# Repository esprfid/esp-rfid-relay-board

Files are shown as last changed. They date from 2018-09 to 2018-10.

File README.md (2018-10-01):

# ESP-RFID Relay Board

This project is follow up for "ESP-RFID Board" but with few more options.

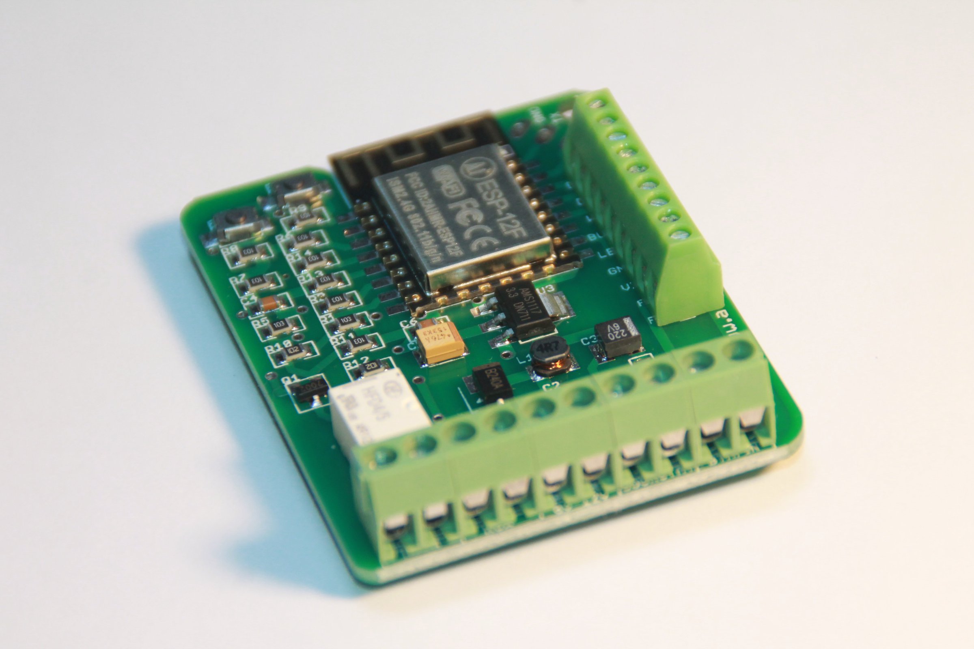
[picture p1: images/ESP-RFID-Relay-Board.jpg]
&nbsp;&nbsp;

## What is ESP-RFID Relay Board?
ESP-RFID Relay Board is tiny ESP12 module (ESP8266) board, designed with wiegand RFID readers in mind and [ESP-RFID Firmware](https://github.com/esprfid/esp-rfid)

* Small size factor, sometimes possible to glue it into existing readers.
* Single power source to power 12V/2A powers ESP12 module, RFID Wiegand Reader and magnetic lock for opening doors.
* Exposed programming pins for ESP8266
* Due to interesting hardware design, you get multiple possible setup options:
  * Forward Bell ringing on reader to MCU or pass it out of board
  * Track Door Status
  * Control reader’s status LED
  * Control reader’s status BUZZER sound
  * Power reader, lock and the board through single 12V, 2A PSU
  * Optionally power magnetic lock through external AC/DC PSU
  * Possible to use any kind and any type of wiegand readers
  * Enables you to make IOT Access System with very litle wiring
  * Fit in universal enclosures with DIN mount
* Opensource Hardware/Cloud RFID reader/Wifi RFID reader

## Wiring example:

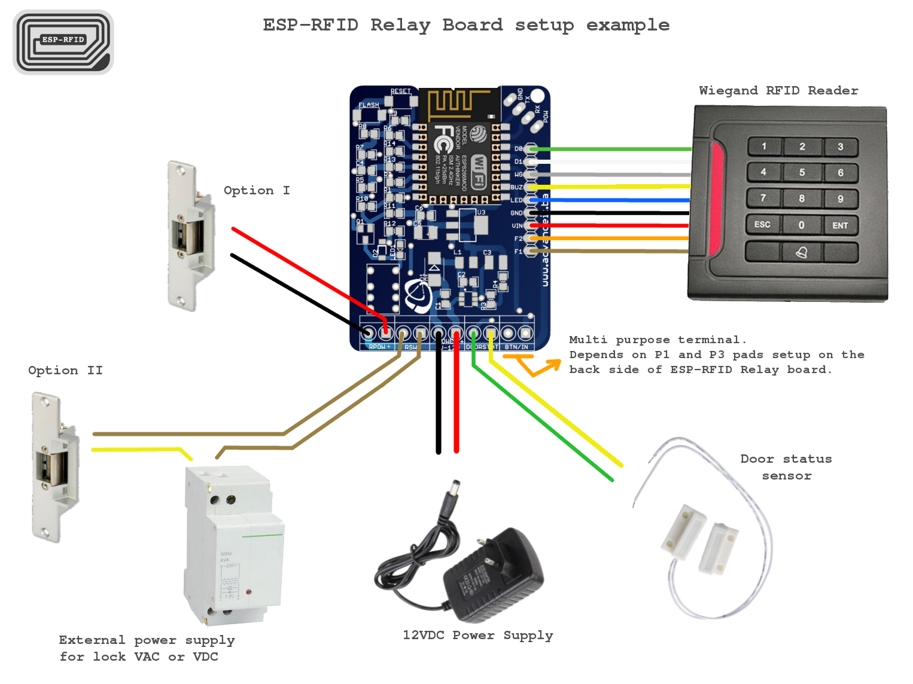
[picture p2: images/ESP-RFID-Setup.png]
&nbsp;&nbsp;

## RESET and FLASH Buttons
Same as for any other ESP8266 programmer where you need to put EPS8266 into a specific mode. If you want to upload your program, you would use this buttons to put ESP8266 into FLASH mode. Check programming procedure down.

## Reader 9 pin terminal
The reason for 9 pins is to cover the most complex wiegand reader i could fins on the market. Mostly they only have 5 or 6 wires but sometimes, they also have 9 wire versions.

**PINNAME**|**CONNECTION**|**DESCRIPTION**
:-----|:-----|:-----
**DO**|GPIO4|Wiegand data line **D0** (*)
**D1**|GPIO5|Wiegand data line **D1**. (*)
**WG**|GPIO0|Some readers have WG line which if HIGH/LOW can change Wiegand stream bits. Usually not very important!
**BUZ**|GPIO12|Almost always Wiegand RFID Readers have Buzzer line which can control piezo buzzer. Due to some inconsistency among readers, i was able to make it work only when i connect this line through 10K resistor and than control it with changing HIGH/LOW on that particular pin, depending what i want. IMPORTANT: **P3** Pad on the back of board, can make that line to be connected directly to GPIO or through 10k resistor. Check **P3** Pad explanation.
**LED**|GPIO15|Most Wiegand readers have RED/GREEN status LEDs. Some color is default and if the line is changed HIGH/LOW than the other color appears.
**GND**|GND|Planned for Wiegand RFID Reader GND.
**VIN**|VIN|Connected directly to board’s POWER terminal’s positive pole. (*)
**F2**|To BTN/IN terminal left pole or to  GPIO14 (**)|Rarely Wiegand RFID Readers incorporate one button which is often doorbell switch, but the version that i took as an example for this board has those wires. It’s simply the switch between F1/F2.
**F1**|To BTN/IN terminal right pole or to GPIO14 (**)|

## Screw Terminals On the bottom of ESP-RFID Relay Board

**TERMINAL NAME**|**DESCRIPTION**
:-----|:-----
**RPOW**|In case **RELAY-POWER** pad is connected, when relay connects the circuit, this terminal provides input voltage directly on it’s poles. So the door magnet lock can be powered directly through this terminal.
**RSW**|Since i used small signal relay, it had two sides so another side is also connecting at the same time when relay makes connection but it only cut circuit. So practical use for this terminal can be to power magnetic lock with external source and even AC so that you get buzzing sound when the lock opens and avoid jamming of the lock. (*)
**POWER 8V-12V**|This is the main power source and in some settings only power source that you need. Please provide minimum 2A if you also power magnetic lock and Wiegand RFID Reader from same source, through ESP-RFID Relay Board
**DOORSTAT**|This terminal was planned to accept door status magnet switch. It can be also repurposed since it’s just a "button" connected to **GPIO16**.
**BTN/IN**|Depending on **P1** and **P2** Pads connection, it can have different purposes.Check **P2/P3** pads description below.

## Configuration pads P1, P2, P3, RELAY-POWER, 5V/3V3

**PAD NAME**|**DESCRIPTION**
:-----|:-----
**P1**|**Options:** Connected poles **3** and **2** redirects **F1** on **RFID Reader Terminal** to **BTN/IN** right pole. Connected poles 3 and 1 and you will get **GPIO14** to be connected on left **BTN/IN** terminal, grounded with 10k resistor. Connected poles **2** and **1** and you will power pin **F1** on **RFID Reader Terminal** with **GPIO14** (*)
**P2**|**Options:** Connected poles **3** and **2** redirects **F2** on  RFID Reader Terminal to BTN/IN left pole. Connected poles 3 and 1 and you will get 3V3 on left pin of BTN/IN terminal. Connected poles **2** and **1** and you will power pin **F2** on **RFID Reader Terminal** with 3V3 (*)
**P3**|**Options:** Connected poles **1** and **2** redirects **BUZ** pin on **RFID Reader Terminal** and **GPIO12**. Connected poles **2** and **3** redirects **BUZ** pin on **RFID Reader Terminal** and **GPIO12** through 10K resistor.
**RELAY-POWER**| This pad is usually connected if you want to power **RPOW** Terminal from main power source as **ESP-RFID Relay Board**
**5V/3V3**|Only purpose of this pad is to connect 5V or 3V3 line to **PROG’s** **POW** pin.

## Pads and what was the idea.
The main idea was to be able to adjust this little board to your scenario and also not  to occupy few GPIO where there is possibility to use those in some other way.

For example, i thought that somebody would like to have remote doorbell but somebody would simple hook it directly. Yet, it might happen that you don’t need doorbell at all but you might find use for GPIO14. So, i made custom PCB Three Way Pad.

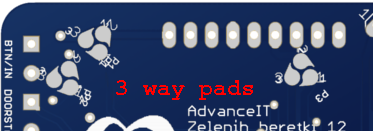
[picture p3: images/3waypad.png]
&nbsp;&nbsp;

Find out about it here:  
https://hackaday.io/project/54277-3-way-pcb-pad  
https://github.com/nardev/eagle3wayPCBpads  
So, it’s similar to other pads which you just solder but this pad has unique shape so it can be soldered not in 2 but in 3 different ways. Just solder it in a way you want. (*) Check the table with description above.

**P1 and P2** pads must be set in pair. Essentially you can get one of three different options.  
**I** : You can redirect F1 and F2 on RFID Reader Terminal to BTN/IN terminal.  
**II**: You can redirect input on F1 and F2 on RFID Reader Terminal to ESP8266’s GPIO14.  
**III**: You can redirect BTN/IN terminal to ESP8266’s GPIO14 as button input.  

**P3** has bit strange purpose. I noticed that most popular wiegand readers have BUZZER line which i couldn’t control directly by simply HIGH/LOW on digital pins of ESP8266 and i also couldn’t  find any docs what signal is required, but i found a way for most of readers, it’s simply to put 10K resistor on the line. But, since it varies i also left an option to hook it directly to GPIO12  

**RELAY-POWER** is just connecting positive line to RPOW terminal. Usually, if you power the lock from the ESP-RFID Relay Board, that pad will be connected and you will use RPOW terminal to hook the lock.  

**5V/3V3** pad can be handy if you are powering ESP12F module through programmer itself while programming.  

## Relay
The relay used on this board is HFD4/5, DPST signal relay and it’s controlled through **GPIO13** on ESP8266.

## PROGRAMMING
#### Programming procedures and options.

**ESP-RFID relay Board** is essentially dev board extension for **ESP12** modules. As that, it has **RESET** and **FLASH** buttons and the rest of circuit required to put ESP8266 in programming mode.
In order to program the board, you would need **"USB-TTL"** or similar compatible programmer. (I personally like this 1$ one [here](https://www.electrodragon.com/product/usb-ttl-serial-ch340-board/))

**Programming Procedure**

Considering that you already installed required drivers for your OS and that you have programming software already set, follow procedure:
1. Connect your **USB-TTL** programmer to P ROG terminal. (Don’t forget to cross lines, RX to TX and vice versa)
2. Press **FLASH** and **RESET** buttons together.
3. Release **RESET** Button and keep **FLASH** Button pressed for 1-2 sec and than release it too.
4. Now, your ESP8266 should be in **FLASH** mode and you can upload you program.
(*) I noticed that it it doesn’t make any problems if you keep **FLASH** Button pressed and sometimes **ESP8266** won’t start with **FLASH** mode in any other way.

## KNOWN ISSUES
* Silkscreen mistake WG/LED pins should be switched. (To test with base
firmware and setting pins to down/up and to check if that is the case only with
ESP-RFID firmware)

* Sometimes, connected ringing button through board, VAC source and to bell,
causes buck converter to jamm. It could be due to poor wire quality or something
else. But usually if it doesn’t occur immediately on first try, it never appears later.

## Short video walk-through

ESP8266 RFID Wiegand ESP12 Nodemcu (https://youtu.be/rXRt-YkzXZU)

### You can get this board from my Tindie shop:
<a href="https://www.tindie.com/products/nardev/esp-rfid-relay-board-12v-for-esp8266-board/">

</a>

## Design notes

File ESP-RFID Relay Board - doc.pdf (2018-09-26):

## ESP-RFID Relay Board v2.0

ESP-RFID Relay Board is tiny ESP12 module (ESP8266) board, designed with wiegand RFID readers in mind.

■ Small size factor, sometimes possible to glue it into existing readers.
■ Single power source to power 12V/2A powers ESP12 module, RFID Wiegand Reader and magnetic lock for opening doors.
■ Exposed programming pins for ESP8266
■ Regarding hardware design, you get multiple possible setup options:
- Forward Bell ringing on reader to MCU or pass it out of board
- Track Door Status
- Control reader’s status LED
- Control reader’s status BUZZER sound *
- Power reader, lock and the board through single 12V, 2A PSU
- Optionally power magnetic lock through external AC/DC PSU
- Possible to use any kind and any type of wiegand readers
- Enables you to make IOT Access System with very litle wiring ■ Fit in universal enclosures with DIN mount
■ Opensource Hardware
■ Optionally comes with Opensource “esp-rfid” firmware which makes it “single door control” ready device with possibility to add rfid access cards or tokens and handle access systems.

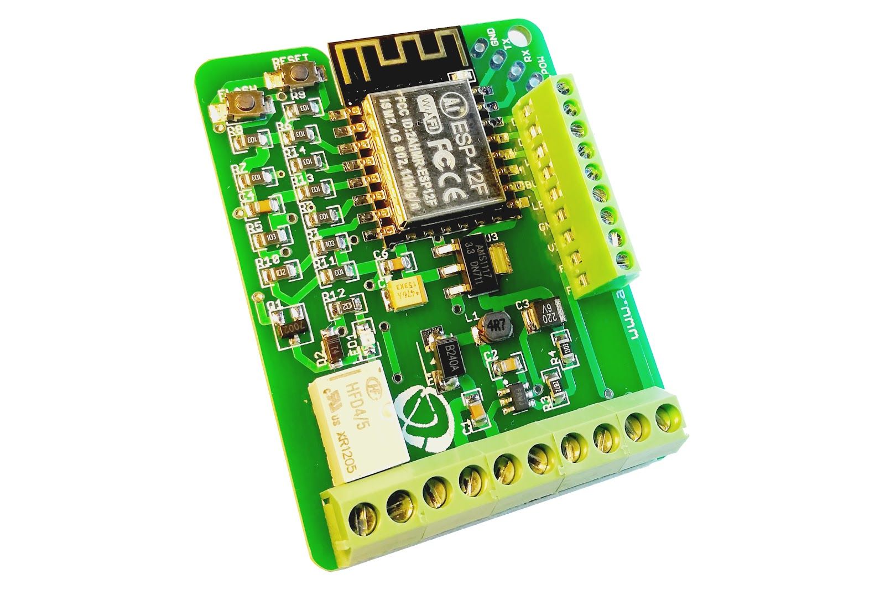
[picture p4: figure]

* This is atypical technical documentation, with a purpose to explain every single part on the board and it’s properties. It’s based mostly on tests and other technical docs for parts that had been used on the board.

AdvanceIT | - ADDRESS: | Džemala Bijedića 129 B/C, Sarajevo, Bosnia & Herzegovina
EMAIL: support@advanceit.ba | TEL: +387 61 107 423 FAX: +387 33 215 206

## HARDWARE EXPLAINED

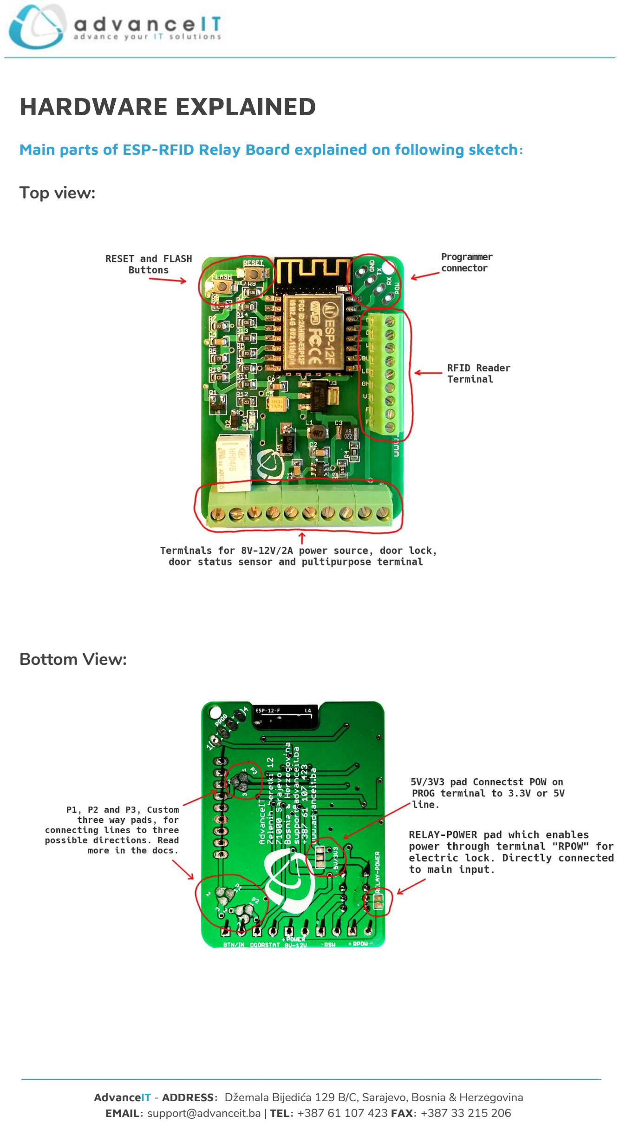
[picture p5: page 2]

Main parts of ESP-RFID Relay Board explained on following sketch:

Top view:

Bottom View:

RESET and FLASH Buttons

Same as for any other ESP8266 programmer where you need to put EPS8266 into a specific mode. If you want to upload your program, you would use this buttons to put ESP8266 into FLASH mode. Check programming procedure down.

RFID Reader Terminal

The reason for 9 pins is to cover the most complex wiegand reader i could fins on the market. Mostly they only have 5 or 6 wires but sometimes, they also have 9 wire versions.

This particular model of Wiegand RFID Reader has 9 wires and 9 pin connector on ESP-RFID Relay Board can handle all those lines.

PIN NAME | CONNECTION | DESCRIPTION
DO | GPIO4 | Wiegand data line D0 (*)
D1 | GPIO5 | Wiegand data line D1. (*)
WG | GPIO0 | Some readers have WG line which if HIGH/LOW can change Wiegand stream bits. Usually not very important!
BUZ | GPIO12 | Almost always Wiegand RFID Readers have Buzzer line which can control piezo buzzer. Due to some inconsistency among readers, i was able to make it work only when i connect this line through 10K resistor and than control it with changing HIGH/LOW on that particular pin, depending what i want. IMPORTANT: P3 Pad on the back of board, can make that line to be connected directly to GPIO or through 10k resistor. Check P3 Pad explanation.
LED | GPIO15 | Most Wiegand readers have RED/GREEN status LEDs. Some color is default and if the line is changed HIGH/LOW than the other color appears.
GND | GND | Planned for Wiegand RFID Reader GND.
VIN | VIN | Connected directly to board’s POWER terminal’s positive pole. (*)
F2 | To BTN/IN terminal left pole or to GPIO14 (**) | Rarely Wiegand RFID Readers incorporate one button which is often doorbell switch, but the version that i took as an example for this board has those wires. It’s simply the switch between F1/F2.
F1 | To BTN/IN terminal right pole or to GPIO14 (**)

(*) Usually Wiegand RFID Readers can work with 8V to 12V as the ESP-RFID relay Board. So, single power supply directly powers both devices.

(**) F1/F2 can be transferred to BTN/IN terminal or to GPIO14, depending on P1/P2 configuration. Check P1/P2 Pads configuration properties below.

Screw Terminals On the bottom of ESP-RFID Relay Board

TERMINAL NAME | DESCRIPTION
RPOW | In case RELAY-POWER pad is connected, when relay connects the circuit, this terminal provides input voltage directly on it’s poles. So the door magnet lock can be powered directly through this terminal.
RSW | Since i used small signal relay, it had two sides so another side is also connecting at the same time when relay makes connection but it only cus circuit. So practical use for this terminal can be to power magnetic lock with external source and even AC so that you get buzzing sound when the lock opens and avoid jamming of the lock. (*)
POWER 8V-12V | This is the main power source and in some settings only power source that you need. Please provide minimum 2A if you also power magnetic lock and Wiegand RFID Reader from same source, through ESP-RFID Relay Board
DOORSTAT | This terminal was planned to accept door status magnet switch. It can be also repurposed since it’s just a “button” connected to GPIO16.
BTN/IN | Depending on P1 and P2 Pads connection, it can have different purposes.Check P2/P3 pads description below.

Configuration pads P1, P2, P3, RELAY-POWER, 5V/3V3

PAD NAME | DESCRIPTION
P1 | Options: ■ Connected poles 3 and 2 redirects F1 on RFID Reader Terminal to BTN/IN right pole. ■ Connected poles 3 and 1 and you will get GPIO14 to be connected on left BTN/IN terminal, grounded with 10k resistor. ■ Connected poles 2 and 1 and you will power pin F1 on RFID Reader terminal with GPIO14 (*)
P2 | Options: ■ Connected poles 3 and 2 redirects F2 on RFID Reader Terminal to BTN/IN left pole. ■ Connected poles 3 and 1 and you will get 3V3 on left pin of BTN/IN terminal. ■ Connected poles 2 and 1 and you will power pin F2 on RFID Reader terminal with 3V3 (*)
P3 | Options: ■ Connected poles 1 and 2 redirects BUZ pin on RFID Reader Terminal and GPIO12. ■ Connected poles 2 and 3 redirects BUZ pin on RFID Reader terminal and GPIO12 through 10K resistor.
RELAY-POWER | This pad is usually connected if you want to power RPOW Terminal from main power source as ESP-RFID Relay Board
5V/3V3 | Only purpose of this pad is to connect 5V or 3V3 line to PROG’s POW pin.

Pads and what was the idea.
The main idea was to be able to adjust this little board to your scenario and also not to occupy few GPIO where there is possibility to use those in some other way.

For example, i thought that somebody would like to have remote doorbell but somebody would simple hook it directly. Yet, it might happen that you don’t need doorbell at all but you might find use for GPIO14. So, i made custom PCB Three Way Pad.

Find out about it here:
https://hackaday.io/project/54277-3-way-pcb-padhttps://github.com/nardev/eagle3wayPCBpads

So, it’s similar to other pads which you just solder but this pad has unique shape so it can be soldered not in 2 but in 3 different
ways. Just solder it in a way you want. (*) Check the table with
description above.

P1 and P2 pads must be set in pair. Essentially you can get one of three different options.
I : You can redirect F1 and F2 on RFID Reader Terminal to BTN/IN terminal.
II: You can redirect input on F1 and F2 on RFID Reader Terminal to ESP8266’s GPIO14.
III: You can redirect BTN/IN terminal to ESP8266’s GPIO14 as button input.

P3 has bit strange purpose. I noticed that most popular wiegand readers have BUZZER line which i couldn’t control directly by simply HIGH/LOW on digital pins of ESP8266 and i also couldn’t find any docs what signal is required, but i found a way for most of readers, it’s simply to put 10K resistor on the line. But, since it varies i also left an option to hook it directly to GPIO12

RELAY-POWER is just connecting positive line to RPOW terminal. Usually, if you power the lock from the ESP-RFID Relay Board, that pad will be connected and you will use RPOW terminal to hook the lock.

5V/3V3 pad can be handy if you are powering ESP12F module through programmer itself while programming.

Relay

The relay used on this board is HFD4/5, DPST signal relay and it’s controlled through GPIO13 on ESP8266.

## BOARD USAGE OPTIONS

“While designing, the idea was to minimize wiring but to provide few more options which could be useful for some installations.”

What is where on the board:

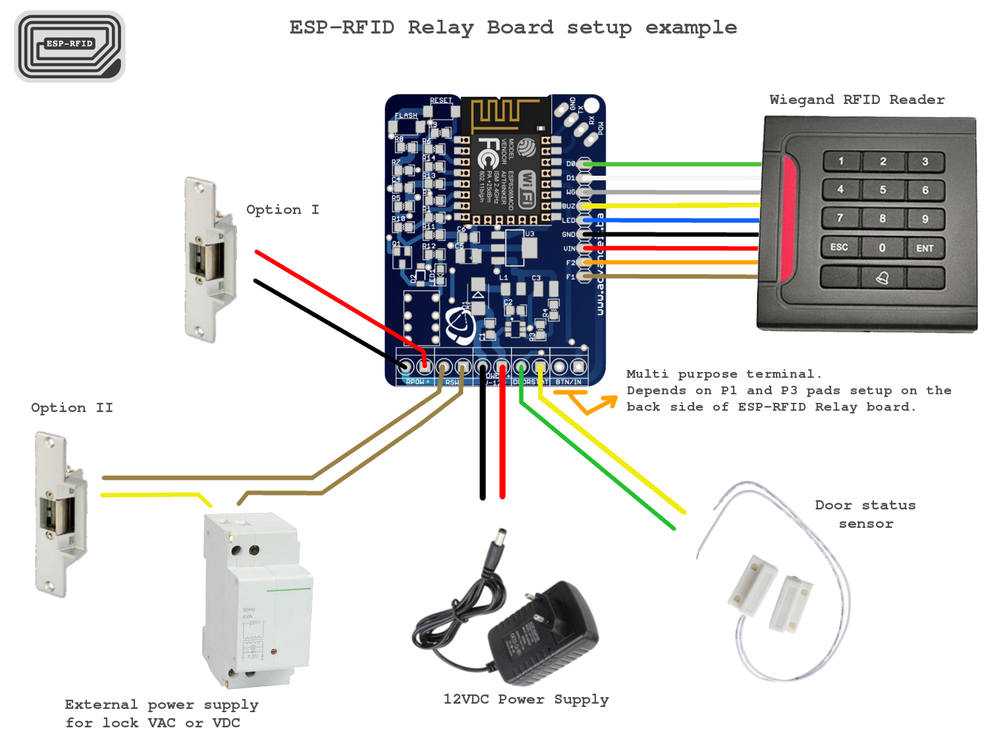
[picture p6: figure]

## I. Most Common Case

■ Single power source 12VDC/2A
■ RFID reader powered directly from the ESP-RFID Board v2.0 ■ Door lock powered directly from the ESP-RFID Board v2.0

[IMAGE/DESCRIPTION COMING SOON]

II. With additional AC Power for Door Lock

■ Main power source 12VDC/2A
■ RFID reader powered directly from the ESP-RFID Board v2.0 ■ Door lock powered directly from the ESP-RFID Board v2.0

[IMAGE/DESCRIPTION COMING SOON]

III. Optional Features

Door status sensor
[IMAGE/DESCRIPTION COMING SOON]

Ring button forward to ESP
Ring button forward to ESP8266

Ring screw terminal as input for sensor or a button
In case it’s not used to forward RING button or Ring is not forwarded to ESP8266, by soldering P1 and P2 …… You can use “BTN/IN” terminal as input to ESP8266.

BUZZER Control
Due to strange behaviour of buzzer, there is there is PAD which can connect the BUZ pin directly to GPIO or through 10K resistor.
[IMAGE/DESCRIPTION COMING SOON]

## POWER SPECIFICATIONS

Power Specifications
There is three levels of voltage on the board. Main input, 5V and 3.3V. Check the description:
Segment | Type of Device | Current/Voltage | Purpose on the board
Required general Input | General purpose 12VDC source | 2A/12V | Main input. Powers everything hooked to a board: - Wiegand RFID reader (~0.5A peak) - ESP-RFID Board (up to 1A max) - Buck Converter - Linear 3V3 Voltage Regulator - Door magnet lock (usually up to 0.5A)
Buck converter | ACT4088 | Lower 12V to 5V / up to ~1A | Power up: - Linear 3V3 Voltage Regulator - Provide 5v for Relay * Possible to pass it to programmer terminal
Linear voltage regulator | LM1117 | Lower 5V to 3.3V / up to ~0.5A | Powering ESP12 module and it’s IO’s. (*) Possible to pass it to programmer terminal
External Power for Relay | AC/DC | 18V/2A | Optional, only if powering door lock or ring.

(*) Please check “5V/3V3” pad purpose.

## PROGRAMMING

Programming procedures and options.
ESP-RFID v2 is essentially dev board extension for ESP12 modules. As that, it has RESET and FLASH buttons and the rest of circuit required to put ESP8266 in programming mode.

In order to program the board, you would need “USB-TTL” or similar compatible programmer. (I personally like this 1$ one here) (http://www.electrodragon.com/product/usb-ttl-serial-ch340-board/)

Programming Procedure

Considering that you already installed required drivers for your OS and that you have programming software already set, follow procedure:

1. Connect your USB-TTL programmer to PROG terminal.
(Don’t forget to cross lines, RX to TX and vice versa)
2. Press FLASH and RESET buttons together.
3. Release RESET Button and keep FLASH Button pressed for 1-2 sec and than release it too.
4. Now, your ESP8266 should be in FLASH mode and you can upload you program.

(*) I noticed that it it doesn’t make any problems if you keep FLASH Button pressed and sometimes ESP8266 won’t start with FLASH mode in any other way.

## KNOWN ISSUES

■ Silkscreen mistake WG/LED pins should be switched. (To test with base firmware and setting pins to down/up and to check if that is the case only with ESP-RFID firmware)
■ Sometimes, connected ringing button through board, VAC source and to bell, causes buck converter to jamm. It could be due to poor wire quality or something else. But usually if it doesn’t occur immediately on first try, it never appears later.

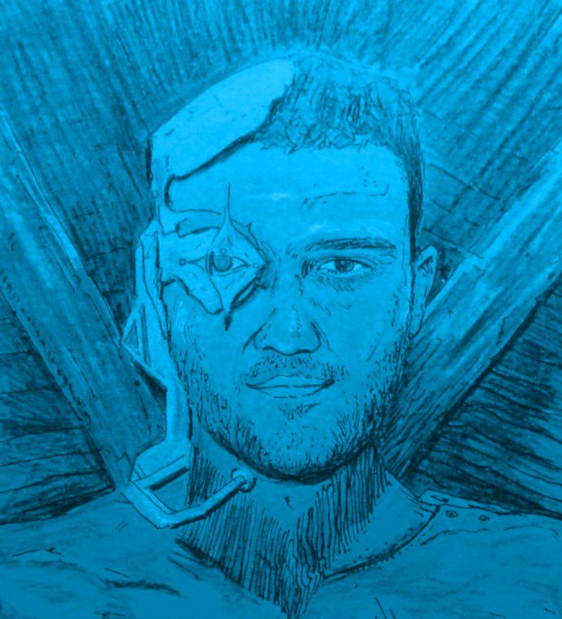
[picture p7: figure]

CONTACT
+387 61 107 423

vedran@advanceit.ba

Džemala Bijedića 129 B/C , Bosnia & Herzegovina

www.advanceit.ba

SOCIAL MEDIA
@e74av (https://www.instagram.com/sfera_antenna/)

@_E74AV_

Vedran Alajbegovic

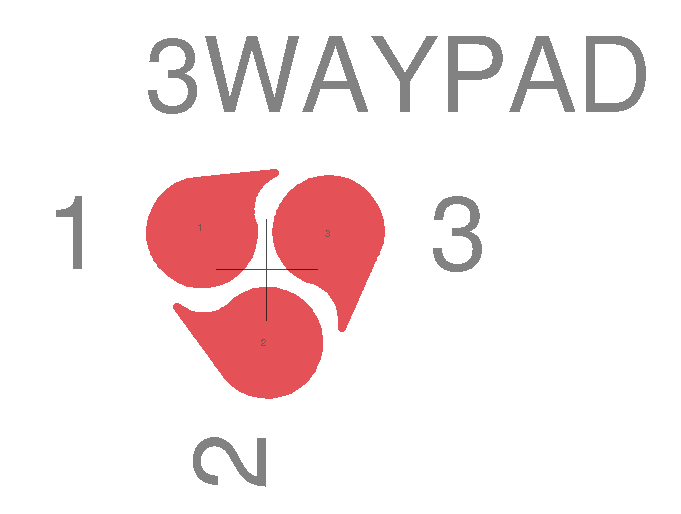
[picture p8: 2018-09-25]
images/3waypadshape.png

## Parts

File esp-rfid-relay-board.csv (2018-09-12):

Part | Value | Device | Package | Description
C1 | 100n | C-EUC0805 | C0805K | CAPACITOR, European symbol
C3 | 22nF | C-EUC0805 | C0805K | CAPACITOR, European symbol
C4 | 10uF | C-EUC0805 | C0805K | CAPACITOR, European symbol
C5 | 220uF | C-EUC1210 | C1210 | CAPACITOR, European symbol
C6 | 0.1uF | C-EUC0805 | C0805K | CAPACITOR, European symbol
D1 |  | SCHOTTKY-DIODESMD | SMB | B240A
D3 | 4007-4148 | DIODESOD123FL | DIO_SOD123FL | 1N4148
L1 | 4.7uH | L-EUL3225M | L3225M | Inductor, can be shielded one if you have.
OP1 |  | LED0805LED | 0805LED | A Led for relay, any color
Q1 |  | MOSFET_NSOT23 | SOT23 | Power MOSFET N-Channel for relay
R7 | 150K | RESISTORR0805 | R0805
R8 | 28.7K | RESISTORR0805 | R0805
R9 | 102R | RESISTORR0805 | R0805
R10 | 15K | RESISTORR0805 | R0805
R12 | 1K / 102R | RESISTORR0805 | R0805
R11 | 10K / 103R | RESISTORR0805 | R0805 | SAME 10K resistors 9
R13 | 10K | RESISTORR0805 | R0805
R14 | 10K | RESISTORR0805 | R0805
R1 | 10K | RESISTORR0805 | R0805
R2 | 10K | RESISTORR0805 | R0805
R3 | 10K | RESISTORR0805 | R0805
R4 | 10K | RESISTORR0805 | v
R5 | 10K | RESISTORR0805 | R0805
R6 | 10K | RESISTORR0805 | R0805
RESET | RESET | BUTTON-2PSWITCH-TURTLE-2P | 2P-SWITCH-TURTLE | Small turtle buttons
FLASH | FLASH | BUTTON-2PSWITCH-TURTLE-2P | 2P-SWITCH-TURTLE
RELAY | 2XSWITCH | 2XSWITCH | HFD3-SIGNAL | Relay HFD3/5V MUST BE 5V version!!!
U2 |  | POWERSOT223 | SOT223 | Voltage Regulator LM1117
BUCKCONV | AIC1896CG-SOT23-6 | ACT4088-(SOT23-6) | SOT-23-6 | ACT4088

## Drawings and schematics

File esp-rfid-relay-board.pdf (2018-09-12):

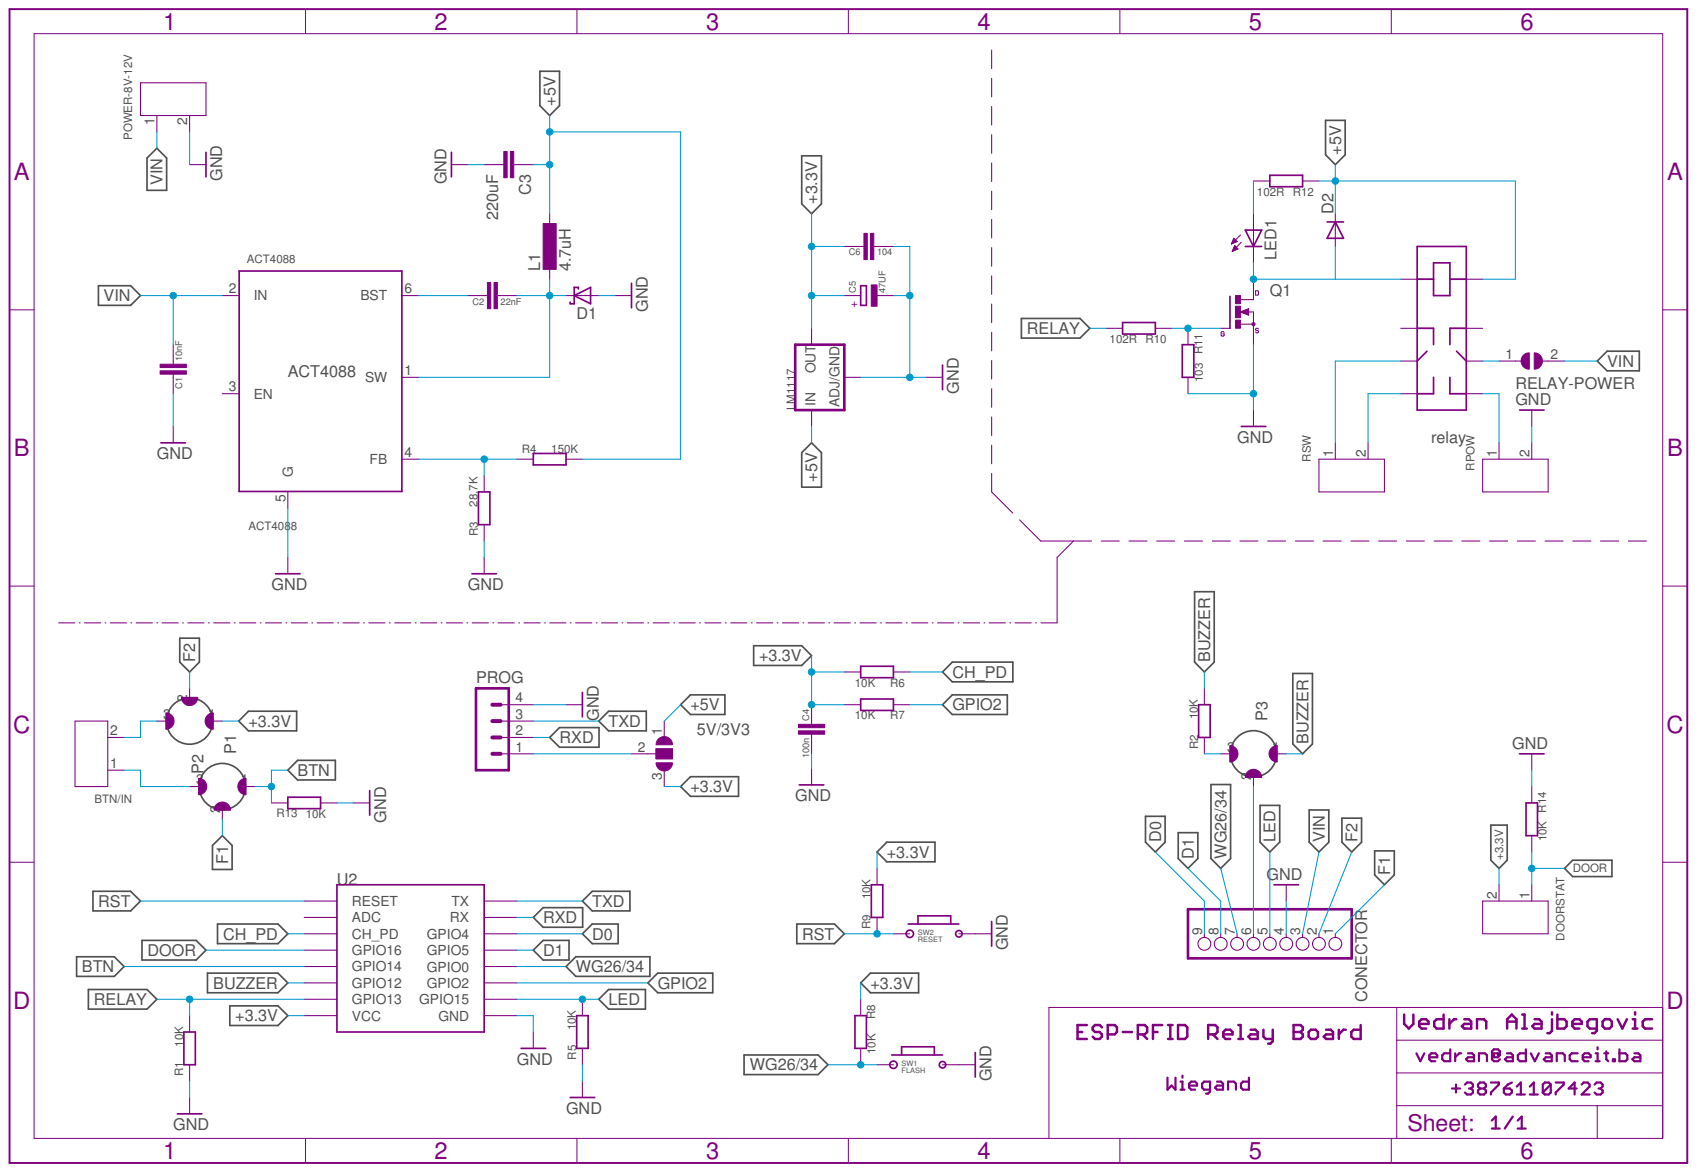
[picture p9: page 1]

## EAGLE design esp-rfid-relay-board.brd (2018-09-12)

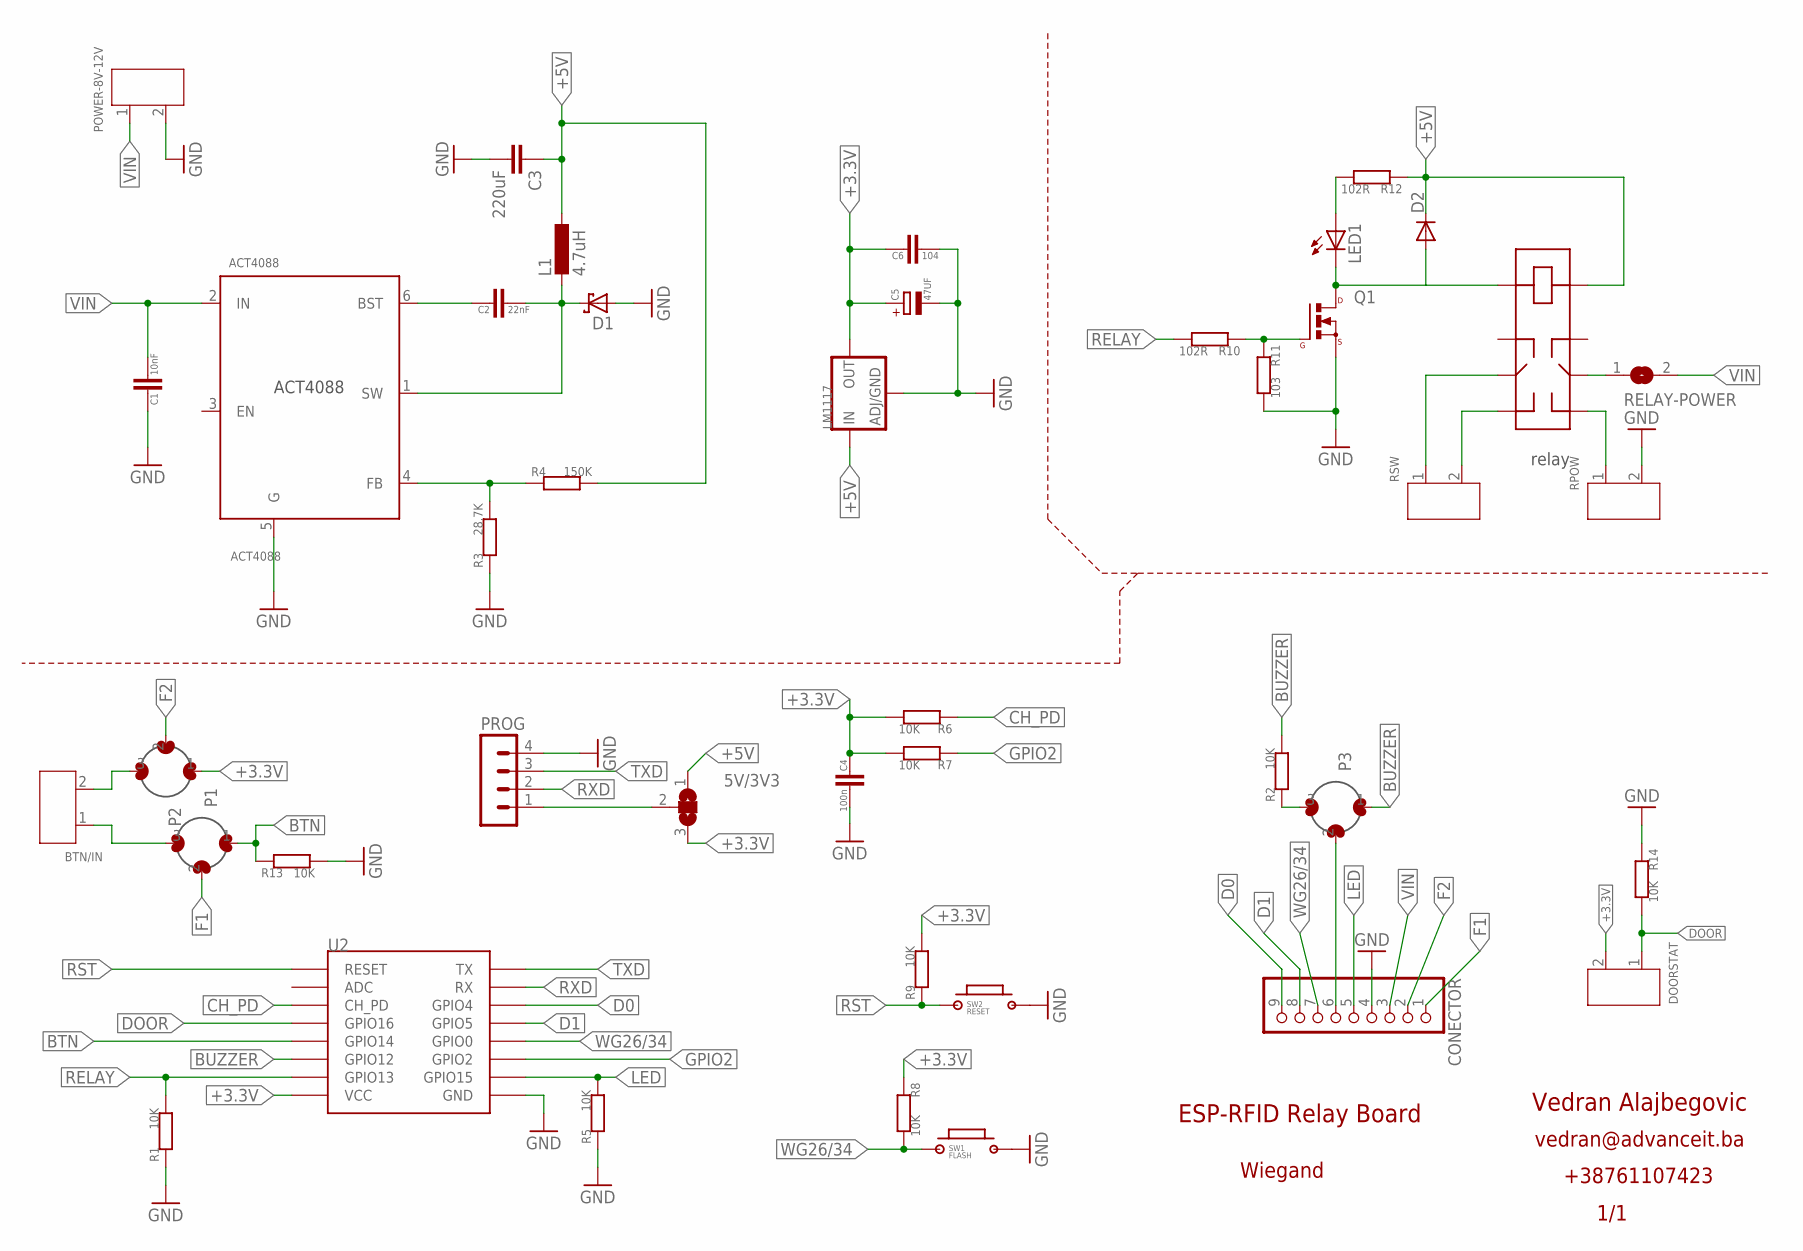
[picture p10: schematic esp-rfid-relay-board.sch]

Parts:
5V/3V3: SJ2W; SJ_2
ACT4088: ACT4088; SOT-23-6
BTN/IN: SCREW-TERMINAL-GREEN(2P-3.5); H2-3.5-7.0X7.0MM
C1: 10nF; C_0805
C2: 22nF; C_0805
C3: 220uF; C1210
C4: 100n; C_0805
C5: 47UF; CPOL_B3528
C6: 104; C_0805
CONECTOR: PINHD-1X9; 1X09
D1: SCHOTTKY-DIODESMD; SMB
D2: 4007-4148; DIO_SOD123FL
DOORSTAT: SCREW-TERMINAL-GREEN(2P-3.5); H2-3.5-7.0X7.0MM
L1: 4.7uH; L3225M
LED1: LED0805LED; 0805LED
LM1117: POWERSOT223; SOT223
P1, P2, P3: SJ3; SJ_3
POWER-8V-12V: SCREW-TERMINAL-GREEN(2P-3.5); H2-3.5-7.0X7.0MM
PROG: MA04-1
Q1: MOSFET_NSOT23; SOT23
R1, R2, R5, R6, R7, R8, R9, R13, R14: 10K; R_0805
R3: 28.7K; R_0805
R4: 150K; R_0805
R10, R12: 102R; R_0805
R11: 103; R_0805
RELAY: 2XSWITCH; HFD3-SIGNAL
RELAY-POWER: SJ
RPOW: SCREW-TERMINAL-GREEN(2P-3.5); H2-3.5-7.0X7.0MM
RSW: SCREW-TERMINAL-GREEN(2P-3.5); H2-3.5-7.0X7.0MM
SW1: FLASH; 2P-SWITCH-TURTLE
SW2: RESET; 2P-SWITCH-TURTLE
U2: ESP12SMD; ESP12-SMD

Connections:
+3.3V: 5V/3V3.3, C4.1, C5.+, C6.1, DOORSTAT.2, LM1117.OUT1 (OUT), LM1117.OUT2 (OUT), P2.1, R6.2, R7.2, R8.1, R9.2, U2.VCC
+5V: 5V/3V3.1, C3.1, D2.C, L1.1, LM1117.IN+ (IN), R4.2, R12.1, RELAY.8
BTN: P1.1, R13.1, U2.GPIO14
BUCK1: ACT4088.1 (SW), C2.2, D1.C, L1.2
BUCK2: ACT4088.4 (FB), R3.2, R4.1
BUCK3: ACT4088.6 (BST), C2.1
BUZZER: P3.1, R2.2, U2.GPIO12
CH_PD: R6.1, U2.CH_PD
D0: CONECTOR.9, U2.GPIO4
D1: CONECTOR.8, U2.GPIO5
DOOR: DOORSTAT.1, R14.2, U2.GPIO16
F1: CONECTOR.1, P1.2
F2: CONECTOR.2, P2.2
GND: ACT4088.5 (G), C1.1, C3.2, C4.2, C5.-, C6.2, CONECTOR.4, D1.A, LM1117.GND, POWER-8V-12V.2, PROG.4, Q1.2 (S), R1.1, R3.1, R5.1, R11.2, R13.2, R14.1, RPOW.2, SW1.2, SW2.2, U2.GND
GPIO2: R7.1, U2.GPIO2
LED: CONECTOR.5, R5.2, U2.GPIO15
unnamed: 5V/3V3.2, PROG.1
unnamed: RELAY.6, RELAY-POWER.1
unnamed: RELAY.5, RPOW.1
unnamed: RELAY.4, RSW.2
unnamed: BTN/IN.1, P1.3
unnamed: BTN/IN.2, P2.3
unnamed: RELAY.3, RSW.1
unnamed: CONECTOR.6, P3.2
unnamed: P3.3, R2.1
RELAY: R1.2, R10.2, U2.GPIO13
RELN1: Q1.1 (G), R10.1, R11.1
RELN2: D2.A, LED1.C, Q1.3 (D), RELAY.1
RELN4: LED1.A, R12.2
RST: R9.1, SW2.1, U2.RESET
RXD: PROG.2, U2.RXD0 (RX)
TXD: PROG.3, U2.TXD0 (TX)
VIN: ACT4088.2 (IN), C1.2, CONECTOR.3, POWER-8V-12V.1, RELAY-POWER.2
WG26/34: CONECTOR.7, R8.2, SW1.1, U2.GPIO0

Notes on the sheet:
relay
Wiegand
Vedran Alajbegovic
vedran@advanceit.ba
+38761107423
ESP-RFID Relay Board
1/1

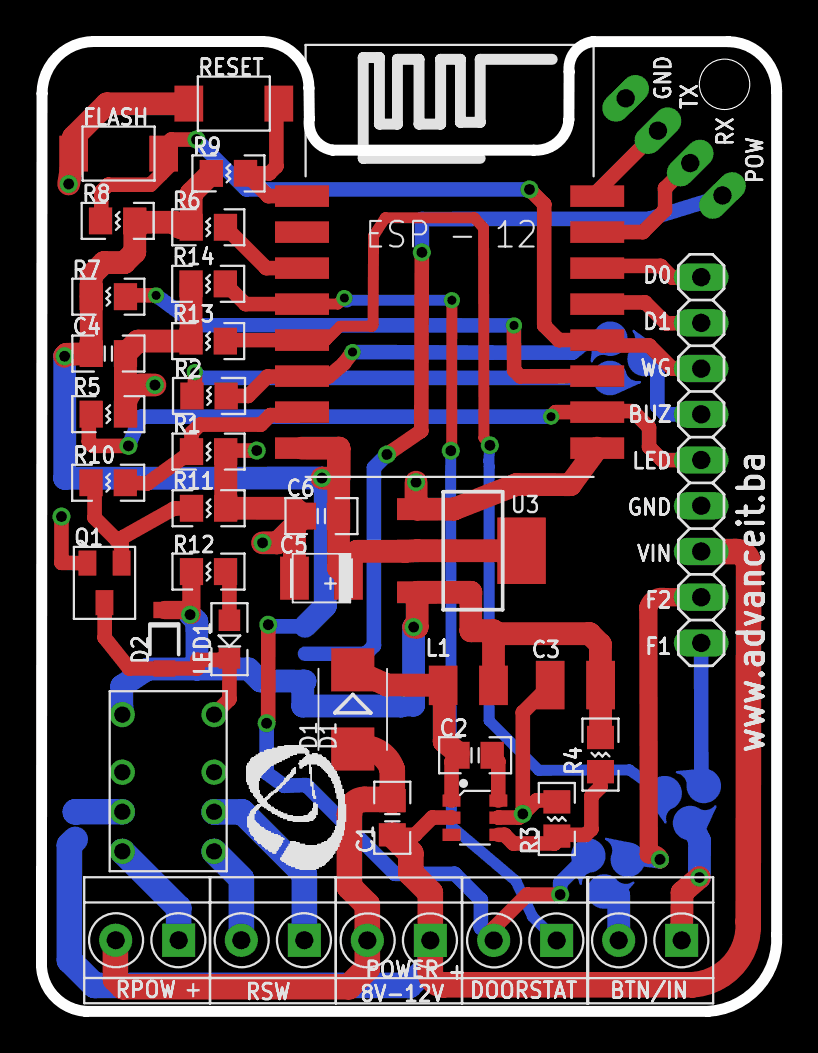
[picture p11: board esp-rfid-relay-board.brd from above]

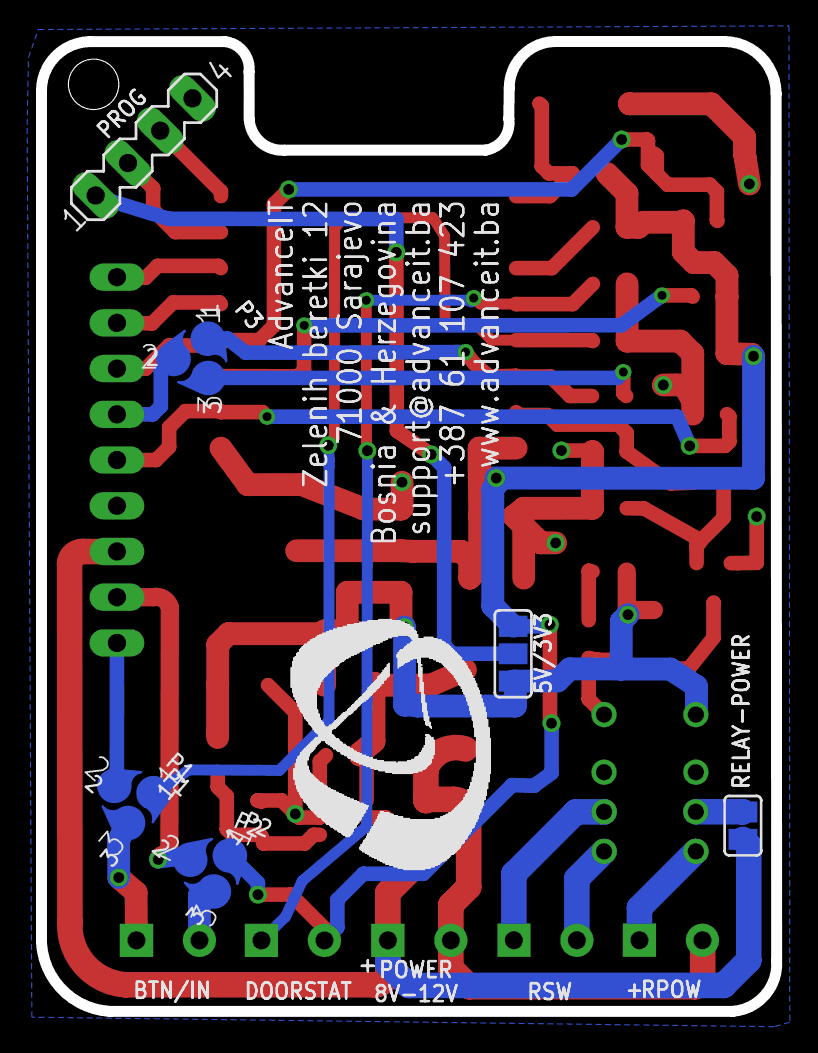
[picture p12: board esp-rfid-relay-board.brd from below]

Board: 2 copper layers, 40.8 x 53.9 mm, 43 parts (6 on the bottom side), 34 nets.

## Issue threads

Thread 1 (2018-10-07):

HW security problem

hexxter, 2018-10-07:
Hi,
an attacker from outside can open the door if he short the 12V on the RFID Reader. Or can kill the electronic by over voltage on the RFID reader pins.

Its better to use the NC pins from the relay. It saves power and if an attacker kills the MCU the door is closed.

BR Hexxter

nardev, 2018-10-09:
Well, true but this is not made for such an environment. And, i don't see which RFID reader and relay board is protected from that @hexxter ?

kratzersemsotec, 2018-10-09:
[RFID_ESP32_schema.pdf](https://github.com/esprfid/esp-rfid-relay-board/files/2461686/RFID_ESP32_schema.pdf)

i have make a short schema with fixes for attackes against the RFID Reader part and cables.
If you short the power (12V) the fuse will break. If you commit power on ground then the diode should help. The other lines are protected via optocopler.

I use an esp32 on my example ;o)

What do you think?

BR Hexxter

nardev, 2018-10-09:
Well, that's great. Polarity protection and isolation is definitely a good thing to add too.

nardev, 2018-10-11:
@kratzersemsotec @hexxter if any of you would like purchase this board, send me an email, i'll give you 50% discount code.

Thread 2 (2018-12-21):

Please help. Pls share the part number for

roysbike, 2018-12-21:
1) D1,,SCHOTTKY-DIODESMD,SMB,B240A- The   complete part number is B240A-13-F    dimension size is SMA?

2) D3,4007-4148,DIODESOD123FL,DIO_SOD123FL,1N4148 -  its ok 1N4148?

Pls   share the part number for

3)C5,220uF,C-EUC1210,C1210,"CAPACITOR,   European symbol" - ?
4) Q1,,MOSFET_NSOT23,SOT23,Power   MOSFET N-Channel for relay- ?
5) RESET,RESET,BUTTON-2PSWITCH-TURTLE-2P,2P-SWITCH-TURTLE,Small   turtle buttons-  ?
6) FLASH,FLASH,BUTTON-2PSWITCH-TURTLE-2P,2P-SWITCH-TURTLE-?
7) RELAY,2XSWITCH,2XSWITCH,HFD3-SIGNAL,Relay   HFD3/5V  MUST BE 5V version!!!- ?
8) U2,,POWERSOT223,SOT223,Voltage Regulator   LM1117-?

nardev, 2019-01-09:
It's quite hard since i didn't go through any supplier specifically.

I'll try to write some tips.

First two are correct. All dimensions can be checked in eagle too.

7. Yes, 5V
8. Yes 3.3V version
4. Yes, n-ch
5. and 6. i think this one fits perfectly: https://www.electrodragon.com/product/34-micro-tactile-push-switch/
3. generic caps.

roysbike, 2019-01-10:
@nardev  thk! C5 220uF ? Realy 220uf or 220 pf, 220nf?

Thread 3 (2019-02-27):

LED, Buzzer, Door Sensor, MQTT

js903801, 2019-02-27:
Hello,
today I received the ESP RFID Relay board and it works fine. I am really excited and want to buy some more.

But I dont know how can I activate the Buzzer an the LED from the Reader?
What about the Door Sensor, I can only see the status at the Event Log.

I would like to read and control everything via MQTT.

js903801, 2019-02-27:
Sorry, I did not mean the door sensor but the bell sensor.

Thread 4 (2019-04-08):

Plans for ESP32

iBobik, 2019-04-08:
Are there some plans to upgrade board to ESP32?

nardev, 2019-11-28:
Still waiting for fw rewrite.

iBobik, 2020-06-11:
Hi, any update on it?

[My FW](https://github.com/esprfid/esp-rfid-py) development is stuck on problems with not enough RAM for features I want, so I look for different HW - some integrated ESP32 board with relay and ~12V power input.

Options:
- https://www.tindie.com/products/jorgeci/simple-developer-relay-board-using-the-esp32-2/
  Seems useable but needs to add 12 to 2.3 V power stabilizer.
- https://www.tindie.com/products/industria_arduino/esp32-industrial-controller-with-wifi-digital-24v/
  Expensive, a lot of features I do not need, seems robust
- https://www.aliexpress.com/item/32878971296.html
  Badly described. Maybe has 12V support, not sure if all needed GPIOs are available

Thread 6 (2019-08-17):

Quite a bit confused about this board

arretx, 2019-08-17:
So I have this board up and running, but I must be misunderstanding something about the terminals.

I have a magnetic lock, 12V.  My understanding is that I simply connect the + and - wires from the lock to the RPOW terminal and I have a functioning lock.  However, I have done so, and the lock is not receiving any power.

There's mention of pads?  I'm not sure if I'm supposed to modify the board or ???  Can you help?

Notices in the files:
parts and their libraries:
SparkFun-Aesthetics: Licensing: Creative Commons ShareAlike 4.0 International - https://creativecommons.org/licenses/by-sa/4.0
